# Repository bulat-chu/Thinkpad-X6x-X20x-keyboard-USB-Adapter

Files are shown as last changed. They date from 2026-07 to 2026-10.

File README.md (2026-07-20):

### ThinkPad X6x/X20x Keyboard USB-C Adapter Project v0.1

This adapter is based on the RP2040 microcontroller and supports QMK firmware.

Currently, only the JIS layout is supported.

Available to purchase on [`tindie`](https://www.tindie.com/products/43186)

**1. QMK firmware source and build files:**
[`Link-to-folder`](https://github.com/bulat-chu/Thinkpad-X6x-X20x-keyboard-USB-Adapter/tree/main/QMK-Firmware/keyboards/Thinkpad_X201_kbd_USB-C)

[`Modified suspend.c file fot ThinkPad like wakeup by pressing only Fn or Power button`](https://github.com/bulat-chu/Thinkpad-X6x-X20x-keyboard-USB-Adapter/blob/main/QMK-Firmware/platforms/suspend.c)

To create your own keyboard layout, edit the `keymap.c` file. The keyboard matrix (row/column mapping) is provided in the `table-*.txt` files.

**2. Schematic**
[`Circuit scheme file`](https://github.com/bulat-chu/Thinkpad-X6x-X20x-keyboard-USB-Adapter/blob/main/Scheme-PCB/Thinkpad_X201_kbd_USB-C-Scheme.pdf)

**3. PCB layout**
[`PCB layout - gerber files`](https://github.com/bulat-chu/Thinkpad-X6x-X20x-keyboard-USB-Adapter/tree/main/Scheme-PCB/PCB-manufacturing-files)

**4. PCB layout**
[`BOM`](https://github.com/bulat-chu/Thinkpad-X6x-X20x-keyboard-USB-Adapter/blob/main/Scheme-PCB/BOM_Thinkpad_X201_kbd_USB-C-Scheme.xlsx)

## Photos

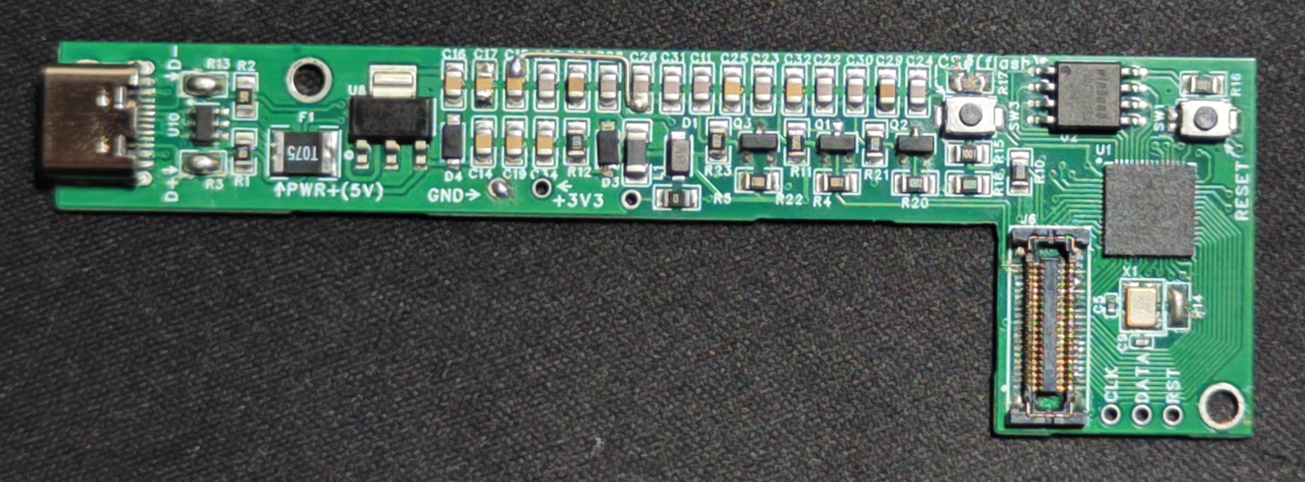
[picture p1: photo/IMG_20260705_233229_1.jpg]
<br>
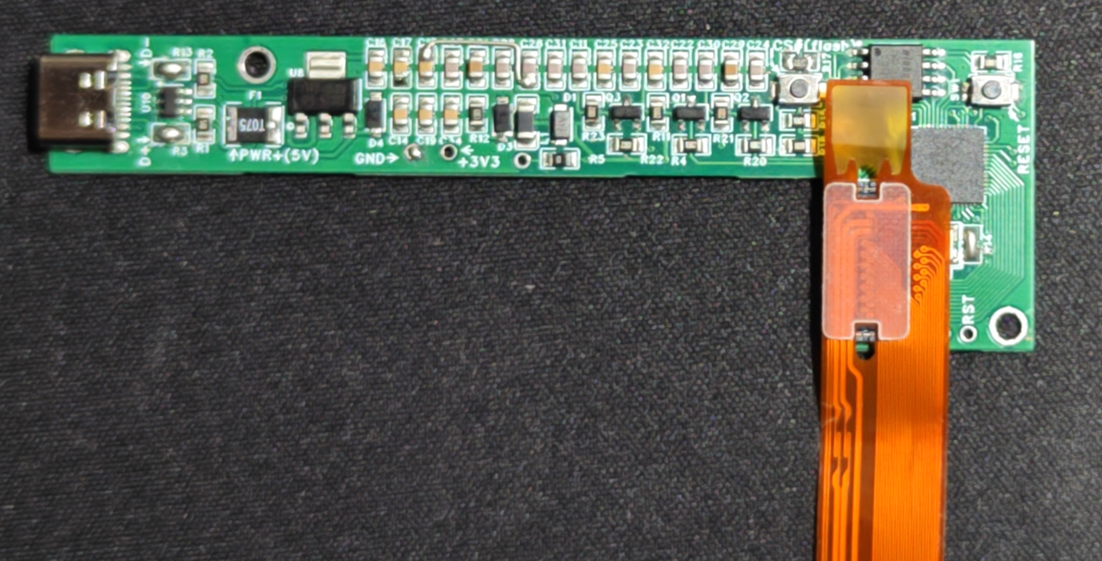
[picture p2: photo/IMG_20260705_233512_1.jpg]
<br>
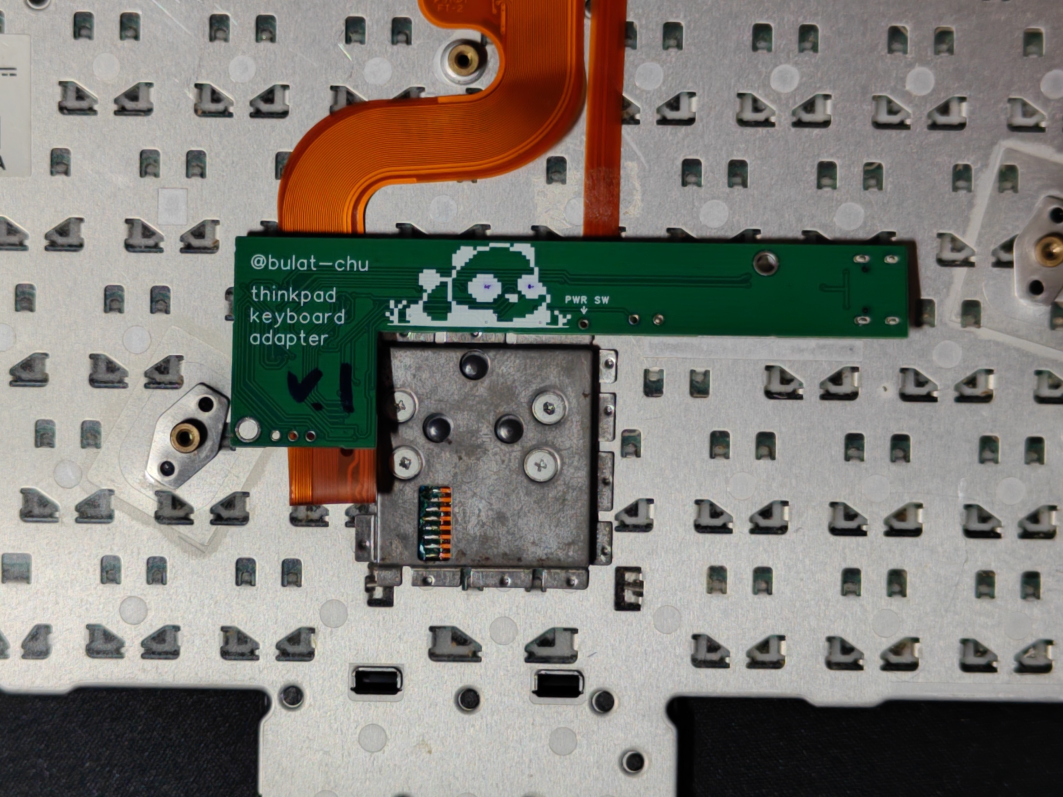
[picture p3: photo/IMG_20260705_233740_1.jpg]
<br>

## Hints

### 1. If HID keys not working

Linux:

1. Download [`Linux-HWDB file`](https://github.com/bulat-chu/Thinkpad-X6x-X20x-keyboard-USB-Adapter/blob/main/driver-or-hwdb-file/99-thinkpad-x20x-kbd-usb-c.hwdb)

2. And put it into `/etc/udev/hwdb.d/`

3. Update hwdb:
`sudo systemd-hwdb update`
`sudo udevadm trigger`

Windows:
?

### 2. Flashing new QMK firmware

To flash a new firmware (`.uf2` file):

1. Unplug the adapter from USB.
2. Press and hold the **CS# (Flash)** button on the adapter.
3. Plug the adapter into a USB port.
4. Release the button.
5. Copy the `.uf2` file to the `RPI-RP2` drive that appears. The firmware will be flashed automatically, and the adapter will reboot.
6. To verify that everything works correctly, run and press any button:

```bash
qmk console
```

### 3. Direct USB cable connection

You can connect a USB cable directly to the board using the following pads:

* `D-`
* `D+`
* `PWR (+5V)`
* `GND`

These pads are marked with arrows on the PCB.

### 3. Direct power button connection

Connect the laptop's power button cable to the `PWR SW` and `GND` pads.

These pads are marked with arrows on the PCB.

**Note:** `PWR SW` is **active low**. Pressing the keyboard power button shorts the `PWR SW` pad to `GND`.

Depending on the laptop model, the `PWR SW` pad may have approximately 3.3 V present even when the adapter is connected and the button is not pressed.
If required, you can replace the 0 Ω resistor next to the PWR SW pad with a resistor of a different value.

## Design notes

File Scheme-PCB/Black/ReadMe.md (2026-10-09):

This is a new revision of adapter.

Changes:

1. Added easier way to disable a MIC-MUTE-LED for X220 series keyboard.

2. Added easier way to change a POWER button input/output for X220 series keyboard (marked as VOL-LED 1 2 3). 

(pin "1" connected to LED-VOL-MUTE in keyboard connector. pin "2" connected to RP2040 GPIO4. pin "3" connected to PWRSWITCH on keyboard connector and "PWR SW" on PCB)

3. Fixed internal +3V3 connection (in the Green version it was fixed with a soldered wire)

4. Added dedicated USB pads

5. Changed PR2040 debug pads to one sided instead of double sided.

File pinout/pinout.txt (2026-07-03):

GPIO Mapping

**SENSE:**
| GPIO | Signal |
|---|---|
| GPIO0 | SENSE5 |
| GPIO1 | SENSE0 |
| GPIO2 | SENSE3 |
| GPIO3 | SENSE2 |
| GPIO5 | SENSE7 |
| GPIO6 | SENSE6 |
| GPIO7 | SENSE1 |
| GPIO8 | SENSE4 |

**DRV:**
| GPIO | Signal |
|---|---|
| GPIO12 | DRV13 |
| GPIO13 | DRV15 |
| GPIO14 | DRV12 |
| GPIO15 | DRV14 |
| GPIO16 | DRV11 |
| GPIO17 | DRV0 |
| GPIO18 | DRV9 |
| GPIO19 | DRV1 |
| GPIO20 | DRV10 |
| GPIO21 | DRV2 |
| GPIO22 | DRV7 |
| GPIO23 | DRV3 |
| GPIO24 | DRV6 |
| GPIO25 | DRV8 |
| GPIO26 | DRV5 |
| GPIO27 | DRV4 |

**TrackPoint PS/2:**
| GPIO | Signal |
|---|---|
| GPIO10 | TP4-DATA-3V3 |
| GPIO11 | TP4-CLK-3V3 |
| GPIO29 | TP4-RESET-3V3 |

**etc:**
| GPIO | Signal |
|---|---|
| GPIO28 | HOTKEY (Fn) |
| GPIO4 | PWRSWITCH (through R5 0Ω) |
| GPIO9 | LED-CAPS-LOCK (through R18 100Ω) |

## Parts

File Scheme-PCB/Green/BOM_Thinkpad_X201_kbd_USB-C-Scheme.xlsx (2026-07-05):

No. | Quantity | Comment | Designator | Footprint | Value
1 | 2 | 33pF | C5,C9 | C0402 | 33pF
2 | 9 | 100nF | C11,C22,C23,C24,C26,C27,C28,C30,C31 | C0805 | 100nF
3 | 8 | 10uF | C14,C15,C16,C17,C19,C25,C32,C34 | C0805 | 10uF
4 | 2 | 1uF | C21,C29 | C0805 | 1uF
5 | 1 | SMF9.0CA | D1 | SMF_L2.9-W1.9-LS3.9-BI
6 | 2 | RB060M-60TR | D3,D4 | SOD-123
7 | 1 | 1812L075PR | F1 | F1812
8 | 1 | AA01B-S040VA1 | J6 | CONN-SMD_AA01B-S040VA1
9 | 1 | FBMJ3216HM600-T | L1 | L1206 | 60Ω
10 | 3 | BSS138 | Q1,Q2,Q3 | SOT-23-3
11 | 2 | 5.1kΩ | R1,R2 | R0805 | 5.1kΩ
12 | 2 | 27Ω | R3,R13 | R0805 | 27Ω
13 | 6 | 10kΩ | R4,R11,R20,R21,R22,R23 | R0805 | 10kΩ
14 | 1 | 0Ω | R5 | R0805 | 0Ω
15 | 2 | 100Ω | R10,R18 | R0805 | 100Ω
16 | 1 | 100kΩ | R12 | R0805 | 100kΩ
17 | 3 | 1kΩ | R14,R15,R16 | R0805 | 1kΩ
18 | 1 | 10kΩ | R17 | R0805 | 10kΩ
19 | 2 | TS-1088-AR02016 | SW1,SW3 | SW-SMD_L3.9-W3.0-P4.45
20 | 1 | RP2040 | U1 | LQFN-56_L7.0-W7.0
21 | 1 | W25Q128JVSIQ | U2 | SOIC-8
22 | 1 | TLV1117LV33DCYR | U8 | SOT-223-3
23 | 1 | SRV05-4 | U10 | SOT-23-6
24 | 1 | TYPE-C-326-16P | USB1 | USB-C-SMD_TYPE-C-311D-16P
25 | 1 | 12MHz | X1 | CRYSTAL-SMD_4P-L3.2-W2.5-BL | 12MHz

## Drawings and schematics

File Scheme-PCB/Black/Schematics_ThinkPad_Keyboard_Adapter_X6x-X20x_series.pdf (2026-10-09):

# QSPI_SD3 51 DVDD ⁵⁰

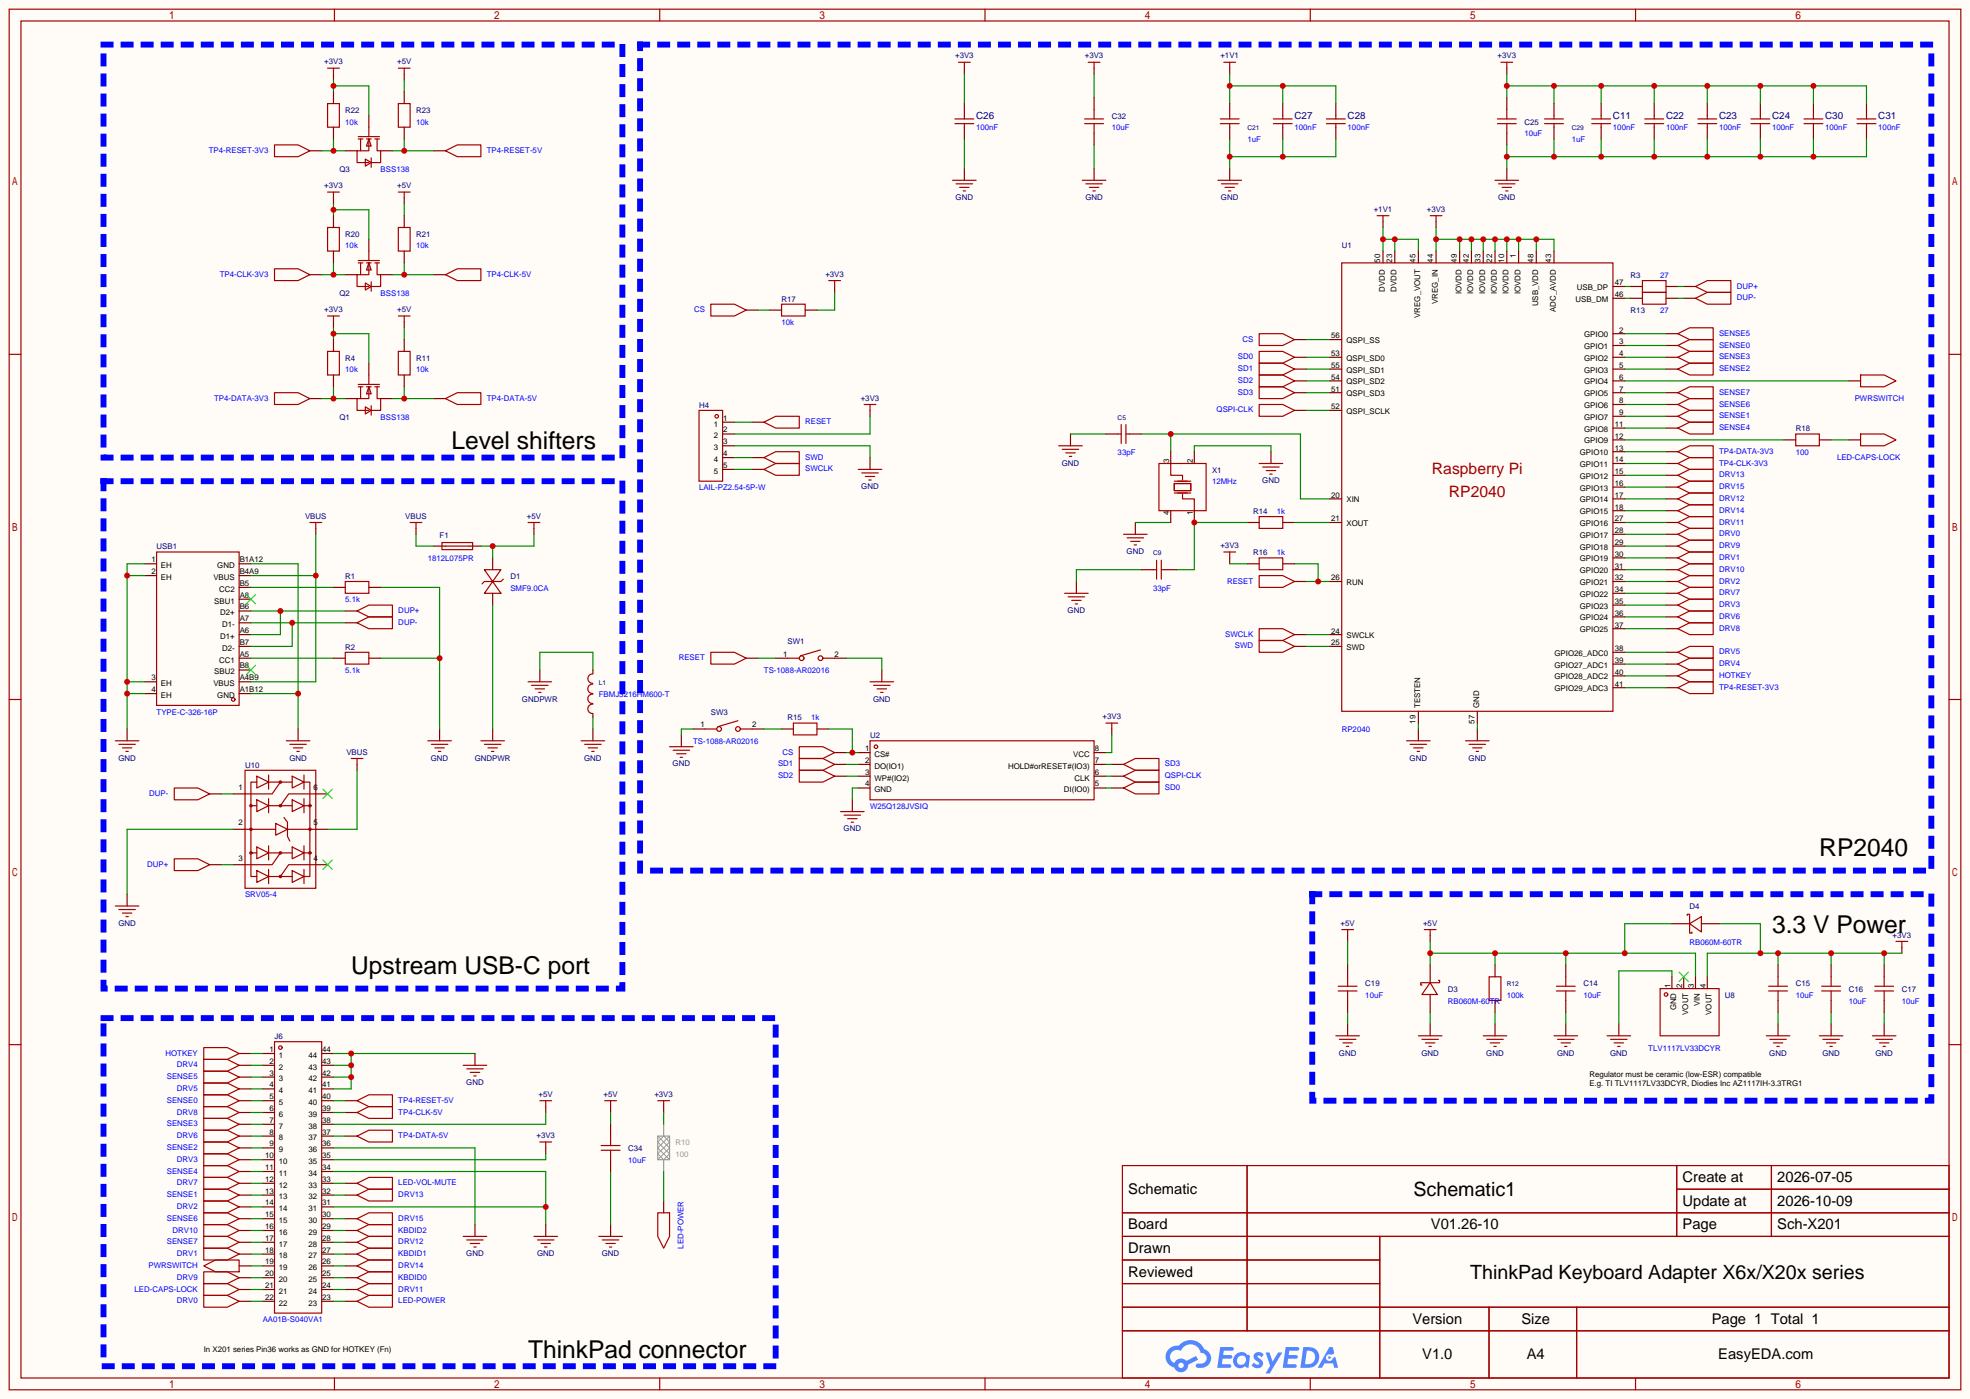
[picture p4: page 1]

Regulator must be ceramic (low-ESR) compatible
E.g. TI TLV1117LV33DCYR, Diodies Inc AZ1117IH-3.3TRG1

Schematic | Schematic1 | Create at | 2026-07-05

Update at | 2026-10-09

Board | V01.26-10 | Page | Sch-X201
Drawn | | ThinkPad Keyboard Adapter X6x/X20x series
Reviewed

Version | Size | Page 1 Total 1
V1.0 | A4 | EasyEDA.com

In X201 series Pin36 works as GND for HOTKEY (Fn)

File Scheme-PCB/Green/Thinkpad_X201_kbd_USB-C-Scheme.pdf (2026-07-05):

# QSPI_SD3 51 DVDD ⁵⁰

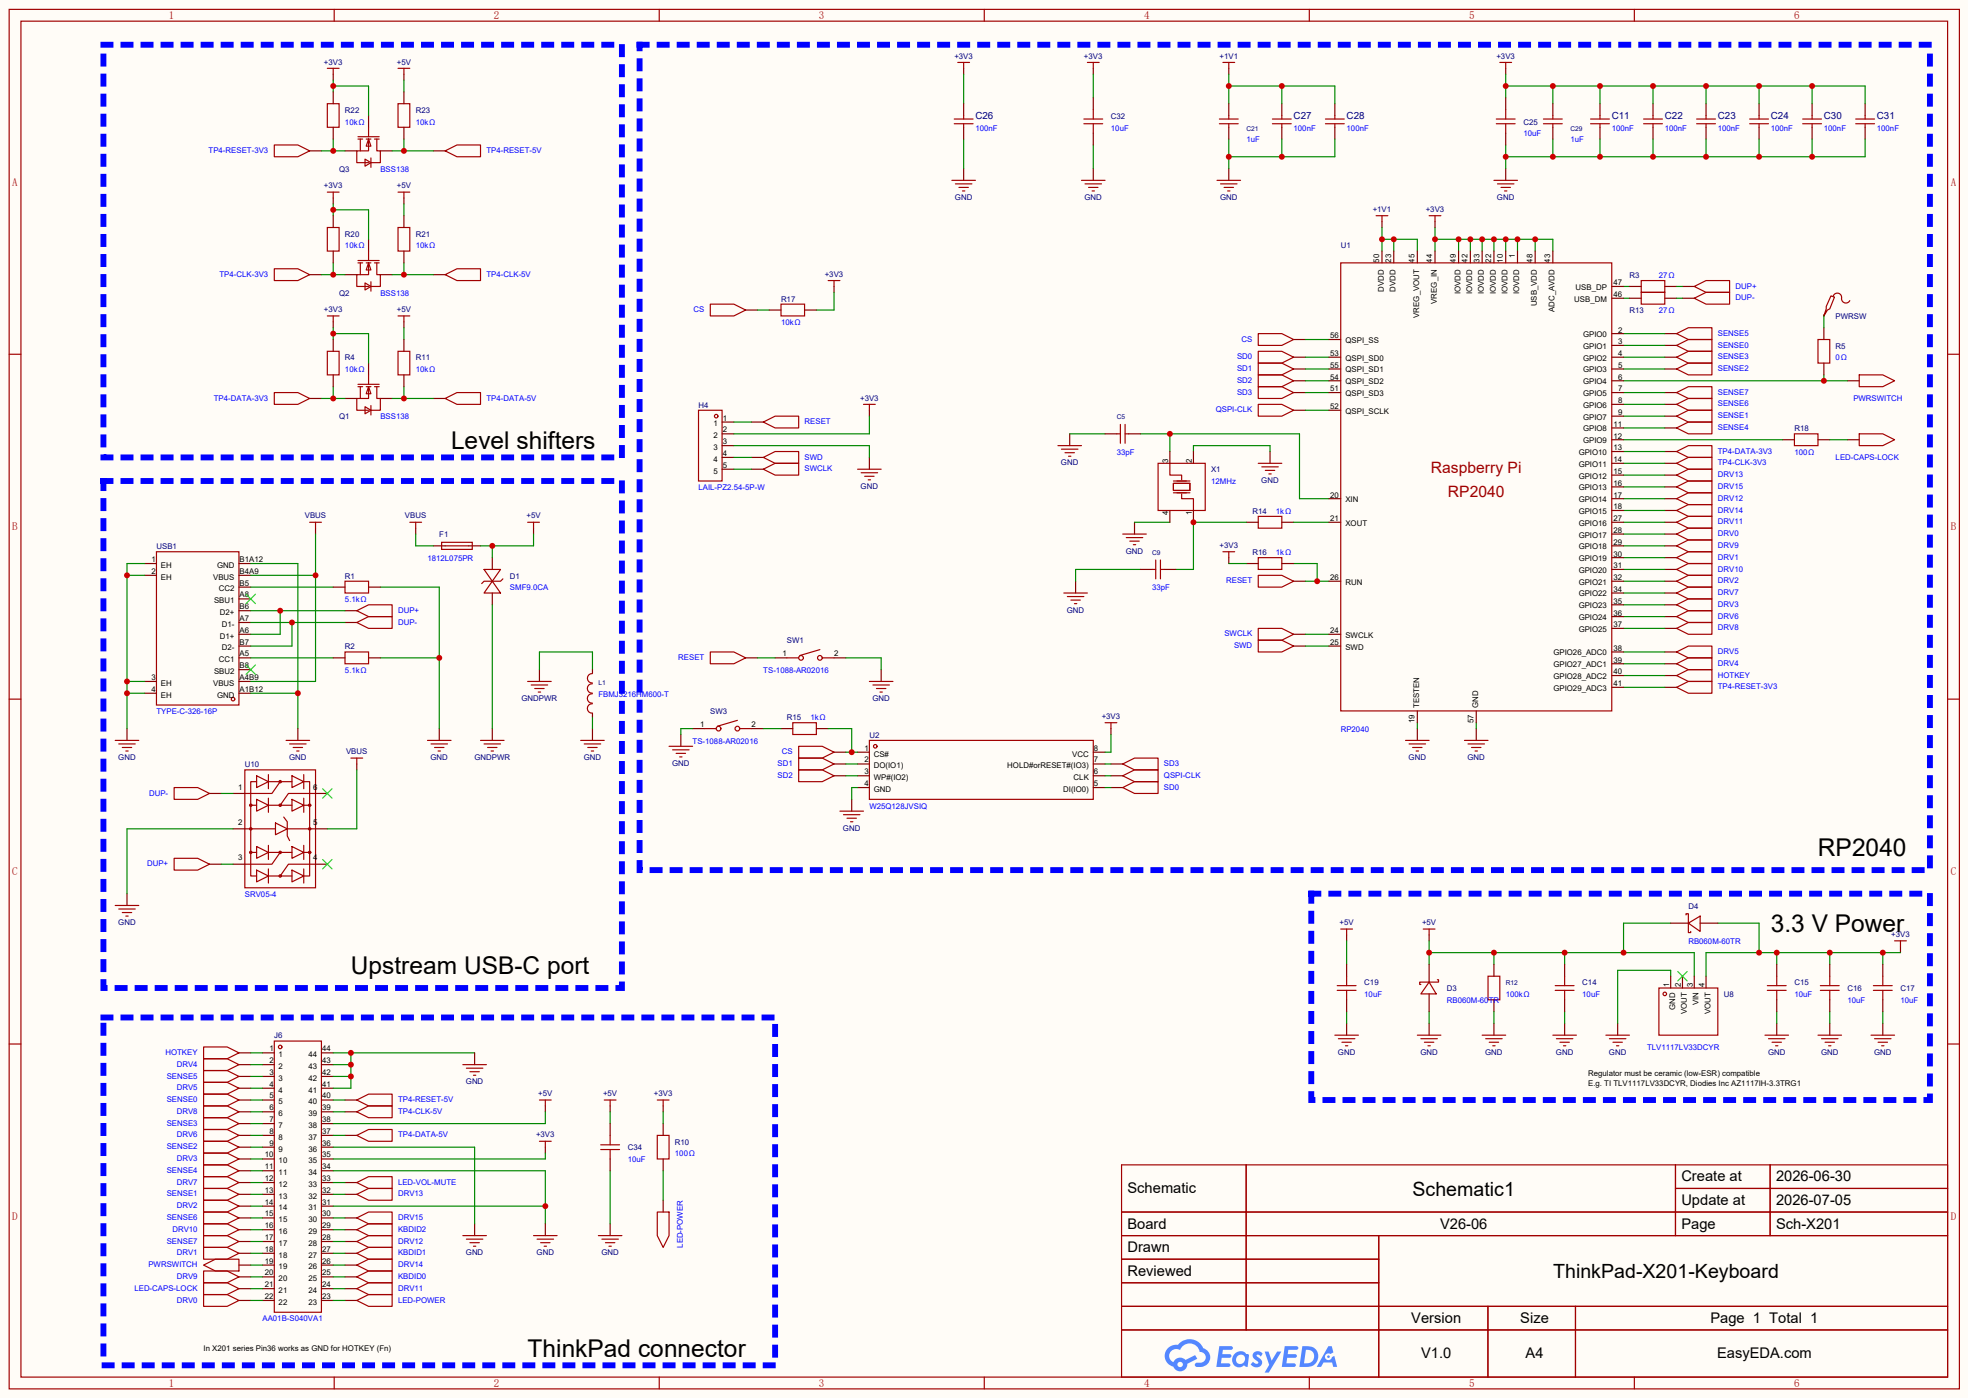
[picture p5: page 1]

Regulator must be ceramic (low-ESR) compatible
E.g. TI TLV1117LV33DCYR, Diodies Inc AZ1117IH-3.3TRG1

Schematic | Schematic1 | Create at | 2026-06-30

Update at | 2026-07-05

Board | V26-06 | Page | Sch-X201
Drawn | | ThinkPad-X201-Keyboard
Reviewed

Version | Size | Page 1 Total 1

In X201 series Pin36 works as GND for HOTKEY (Fn)

V1.0 | A4 | EasyEDA.com

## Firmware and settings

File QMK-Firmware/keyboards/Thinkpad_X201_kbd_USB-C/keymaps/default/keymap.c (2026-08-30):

#include QMK_KEYBOARD_H
#include "keymap_japanese.h"
#include "gpio.h"
#include "host.h"

/*
 * ThinkPad X20x JP keyboard matrix
 * 8 rows (SENSE) x 16 cols (DRV)
 *
 * Layer 0 — main JP
 * Layer 1 — NumPad (toggle via NUM_TOG, follows NumLock state)
 * Layer 2 — Fn (momentary, GP28 active HIGH)
 *
 * GP4  = Power (active LOW, INPUT_PULLUP) — wakes host from suspend
 * GP28 = Fn    (active HIGH, INPUT no pullup)
 * GP29 = TrackPoint RESET (active LOW, OUTPUT)
 * GP10 = TP DATA
 * GP11 = TP CLK
 * GP9  = LED CapsLock
 */

// ---------------------------------------------------------------------------
// Custom keycodes
// ---------------------------------------------------------------------------

static bool suspend_waiting_release = true;
static bool trackpoint_enabled = true;


enum custom_keycodes {
    NUM_TOG = SAFE_RANGE,  // toggle NumLock + layer 1
    CK_SCRSVR,             // XF86ScreenSaver  consumer 0xA0
    CK_BATT,               // XF86Battery      consumer 0xF4
    CK_RFKILL,             // XF86RFKill       consumer 0xF6
    CK_DISP,               // XF86Display      consumer 0xEB
    CK_LNCH1,              // XF86Launch1      consumer 0x9C
    CK_TPDTOG,             // Touchpad Toggle  consumer 0xD4
//    CK_MICMT,              // Mic Mute Toggle  consumer 0xF8
};

// ---------------------------------------------------------------------------
// Keymaps
// ---------------------------------------------------------------------------
const uint16_t PROGMEM keymaps[][MATRIX_ROWS][MATRIX_COLS] = {

    // Layer 0 — main JP
    [0] = {
    //       0           1           2           3           4           5           6           7           8           9           10          11          12          13          14          15
    /* 0 */ {KC_LALT,    KC_NO,      KC_UP,      KC_NO,      KC_NO,      KC_ESC,     KC_NO,      KC_NO,      KC_NO,      KC_F4,      KC_QUOT,    KC_G,       JP_HENK,    KC_F5,      KC_F6,      KC_H    },
    /* 1 */ {KC_NO,      KC_LCTL,    KC_HOME,    KC_NO,      KC_PGUP,    JP_ZKHK,    KC_INS,     KC_F1,      KC_DEL,     KC_F2,      KC_MINS,    KC_5,       KC_F8,      KC_F9,      JP_CIRC,    KC_6    },
    /* 2 */ {KC_NO,      KC_NO,      KC_NO,      KC_LSFT,    KC_NO,      KC_TAB,     KC_LGUI,    KC_CAPS,    KC_VOLD,    KC_F3,      JP_AT,      KC_T,       KC_F7,      KC_BSPC,    JP_LBRC,    KC_Y    },
    /* 3 */ {KC_SCRL,    KC_NO,      KC_NO,      KC_NO,      KC_LGUI,    KC_Q,       KC_NO,      KC_W,       KC_VOLU,    KC_E,       KC_P,       KC_R,       KC_O,       JP_YEN,     KC_I,       KC_U    },
    /* 4 */ {KC_RALT,    KC_NO,      KC_LEFT,    KC_NO,      KC_WFWD,    JP_MHEN,    KC_RGHT,    KC_NO,      KC_DOWN,    KC_NO,      KC_SLSH,    KC_B,       JP_KANA,    KC_SPC,     JP_BSLS,    KC_N    },
    /* 5 */ {KC_NO,      KC_RCTL,    KC_PAUS,    KC_RSFT,    KC_WBAK,    KC_Z,       KC_NO,      KC_X,       KC_F20,      KC_C,       JP_RBRC,    KC_V,       KC_DOT,     KC_ENT,     KC_COMM,    KC_M    },
    /* 6 */ {KC_PSCR,    KC_NO,      KC_END,     KC_NO,      KC_PGDN,    KC_1,       KC_F12,     KC_2,       KC_F11,     KC_3,       KC_0,       KC_4,       KC_9,       KC_F10,     KC_8,       KC_7    },
    /* 7 */ {KC_NO,      KC_NO,      KC_NO,      KC_NO,      KC_APP,     KC_A,       KC_NO,      KC_S,       KC_MUTE,    KC_D,       KC_SCLN,    KC_F,       KC_L,       KC_NO,      KC_K,       KC_J    },
    },

    // Layer 1 — NumPad (toggle, follows NumLock state)
    [1] = {
    //       0           1           2           3           4           5           6           7           8           9           10          11          12          13          14          15
    /* 0 */ {KC_TRNS,    KC_TRNS,    KC_TRNS,    KC_TRNS,    KC_TRNS,    KC_TRNS,    KC_TRNS,    KC_TRNS,    KC_TRNS,    KC_TRNS,    KC_TRNS,    KC_TRNS,    KC_TRNS,    KC_TRNS,    KC_TRNS,    KC_TRNS },
    /* 1 */ {KC_TRNS,    KC_TRNS,    KC_TRNS,    KC_TRNS,    KC_TRNS,    KC_TRNS,    KC_TRNS,    KC_TRNS,    KC_TRNS,    KC_TRNS,    KC_TRNS,    KC_TRNS,    KC_TRNS,    KC_TRNS,    KC_TRNS,    KC_TRNS },
    /* 2 */ {KC_TRNS,    KC_TRNS,    KC_TRNS,    KC_TRNS,    KC_TRNS,    KC_TRNS,    KC_TRNS,    KC_TRNS,    KC_TRNS,    KC_TRNS,    KC_PENT,    KC_TRNS,    KC_TRNS,    KC_TRNS,    KC_TRNS,    KC_TRNS },
    /* 3 */ {NUM_TOG,    KC_TRNS,    KC_TRNS,    KC_TRNS,    KC_TRNS,    KC_TRNS,    KC_TRNS,    KC_TRNS,    KC_TRNS,    KC_TRNS,    KC_PAST,    KC_TRNS,    KC_P6,      KC_TRNS,    KC_P5,      KC_P4   },
    /* 4 */ {KC_TRNS,    KC_TRNS,    KC_TRNS,    KC_TRNS,    KC_TRNS,    KC_TRNS,    KC_TRNS,    KC_TRNS,    KC_TRNS,    KC_TRNS,    KC_PPLS,    KC_TRNS,    KC_TRNS,    KC_TRNS,    KC_TRNS,    KC_TRNS },
    /* 5 */ {KC_TRNS,    KC_TRNS,    KC_TRNS,    KC_TRNS,    KC_TRNS,    KC_TRNS,    KC_TRNS,    KC_TRNS,    KC_TRNS,    KC_TRNS,    KC_TRNS,    KC_TRNS,    KC_PDOT,    KC_TRNS,    KC_TRNS,    KC_P0   },
    /* 6 */ {KC_TRNS,    KC_TRNS,    KC_TRNS,    KC_TRNS,    KC_TRNS,    KC_TRNS,    KC_TRNS,    KC_TRNS,    KC_TRNS,    KC_TRNS,    KC_PSLS,    KC_TRNS,    KC_P9,      KC_TRNS,    KC_P8,      KC_P7   },
    /* 7 */ {KC_TRNS,    KC_TRNS,    KC_TRNS,    KC_TRNS,    KC_TRNS,    KC_TRNS,    KC_TRNS,    KC_TRNS,    KC_TRNS,    KC_TRNS,    KC_PMNS,    KC_TRNS,    KC_P3,      KC_TRNS,    KC_P2,      KC_P1   },
    },
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

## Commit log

2026-07-06 Update README.md
    Modified suspend.c file fot ThinkPad like wakeup by pressing only Fn or Power button
2026-08-30 Update keymap.c
    fix for X220 keyboard
    [keymap.c]
2026-10-09 move files
    [Drill_NPTH_Through.DRL, Drill_PTH_Through.DRL, Drill_PTH_Through_Via.DRL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]
2026-10-26 Revise photos and PCB markings in README
    Updated image links and clarified PCB markings for different colors.
2026-10-26 Update schematics section title in README.md
